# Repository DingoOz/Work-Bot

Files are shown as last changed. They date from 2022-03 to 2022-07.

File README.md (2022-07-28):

# Work-Bot
2022 Semester 2

//TODO
* document code more
* factor the code to use functions more
* document a possible Finite State Machine that calls these functions
* implement a watchdog timer to detect if robot is not making progress

== Diagnostic Routine ==
Possibly create a separate program to act as a diagnostic program to test all functions of the hardward.

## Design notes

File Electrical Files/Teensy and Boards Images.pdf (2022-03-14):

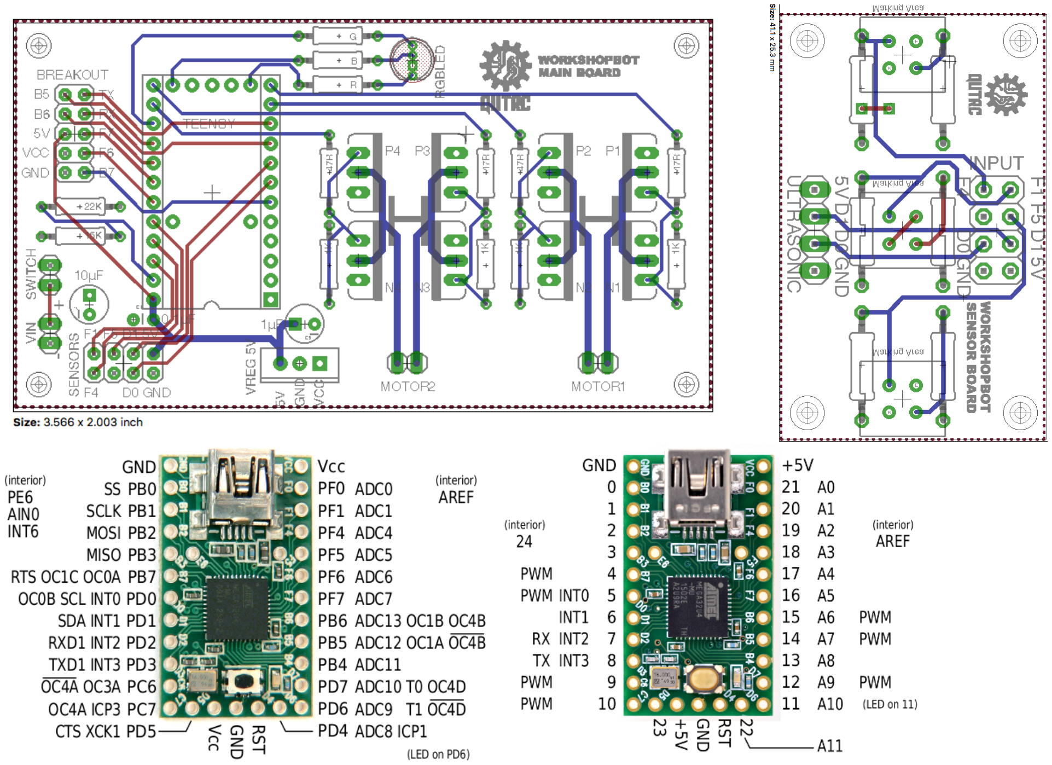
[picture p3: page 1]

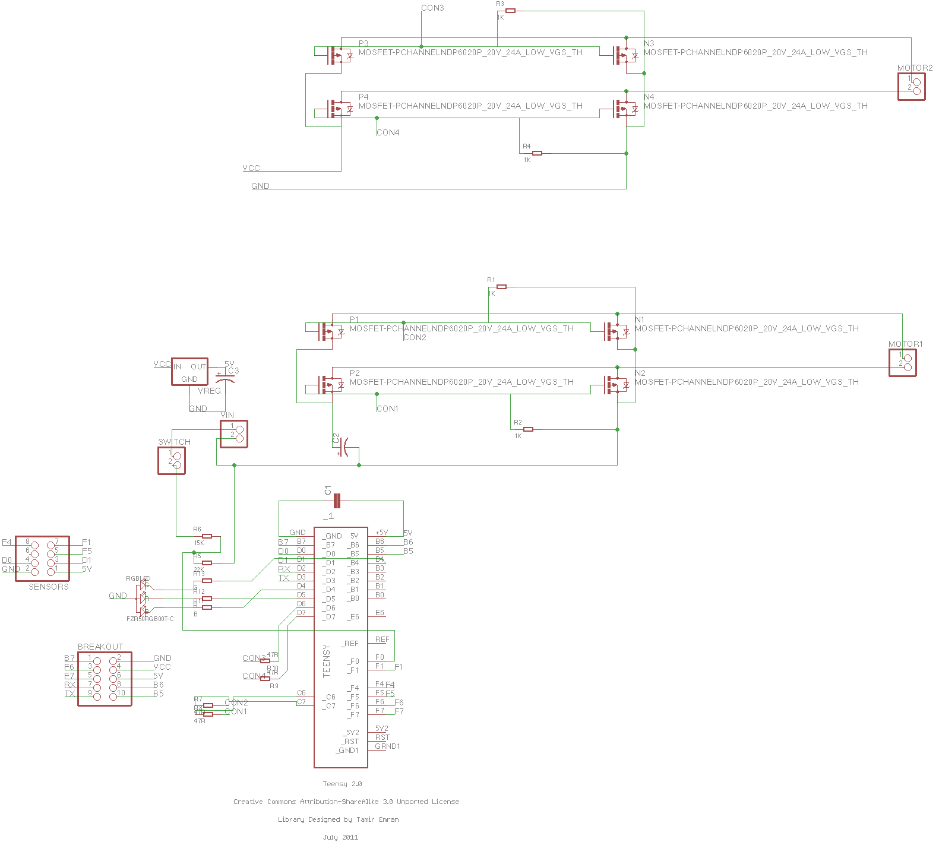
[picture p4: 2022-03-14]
Electrical Files/Workbot2017 - Schematic.png

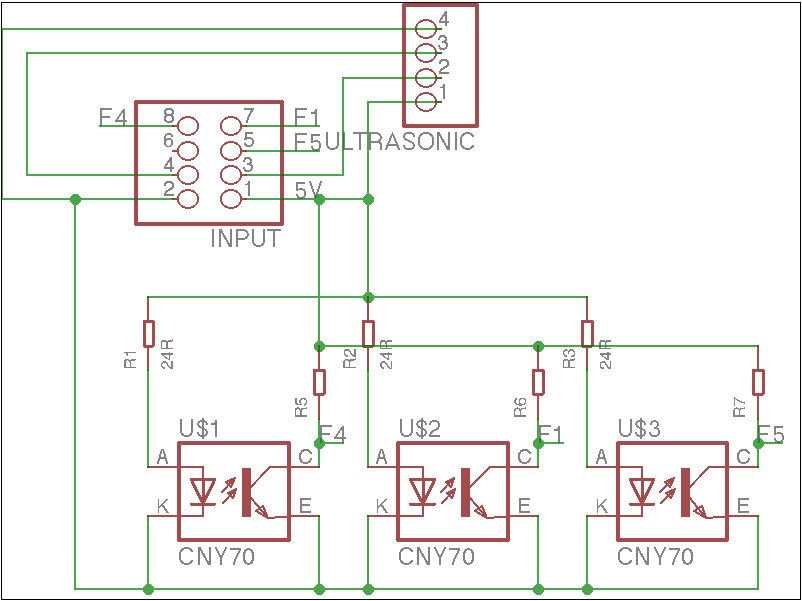
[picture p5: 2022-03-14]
Electrical Files/IR Sensor Schematic.png

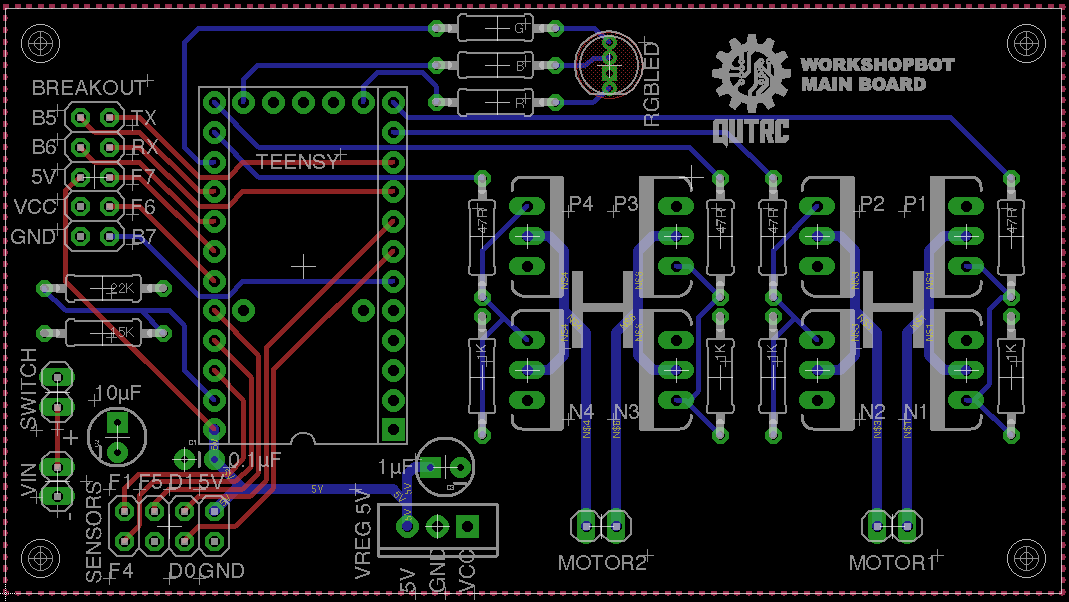
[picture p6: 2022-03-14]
Electrical Files/Main PCB Black.png

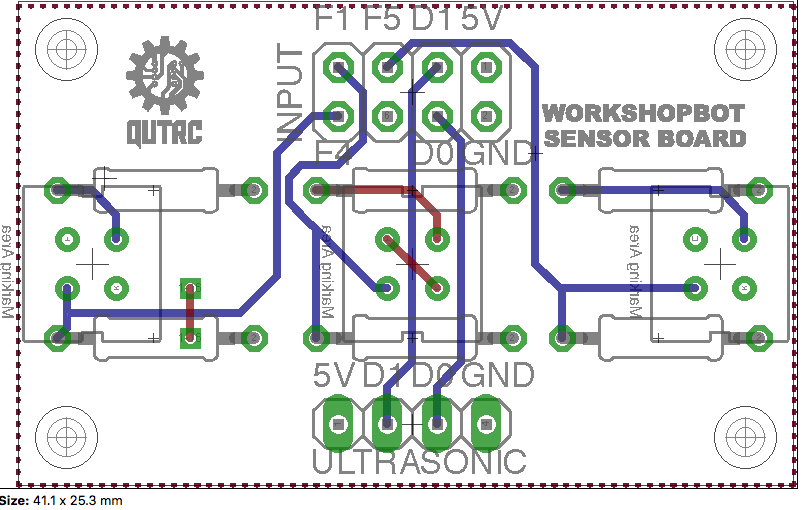
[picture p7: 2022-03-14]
Electrical Files/IR Sensor Board.png

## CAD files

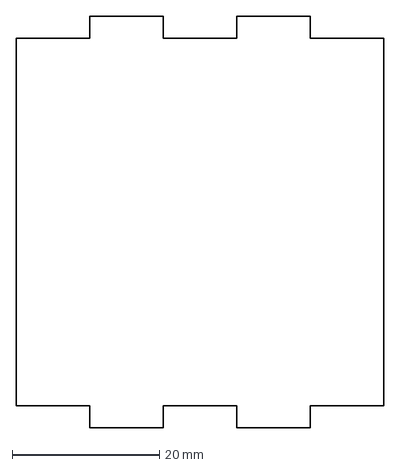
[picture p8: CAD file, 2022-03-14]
Mechanical Files/Top_box.dxf
50.0 x 56.0 mm

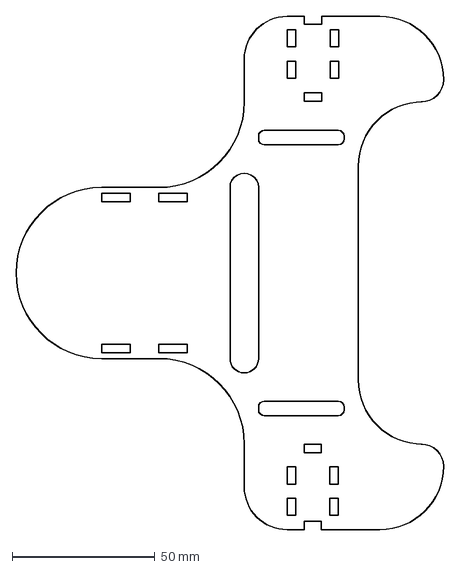
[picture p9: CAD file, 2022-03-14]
Mechanical Files/Torus_base_v1.dxf
150.0 x 180.0 mm

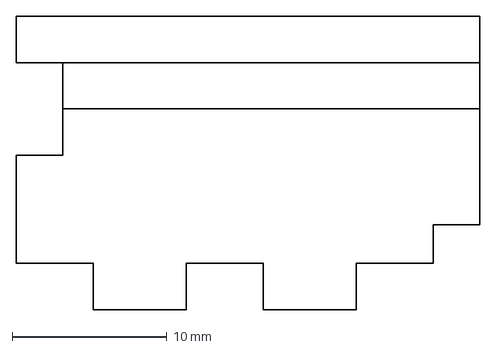
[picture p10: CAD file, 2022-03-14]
Mechanical Files/Motor_side.dxf
30.0 x 19.0 mm

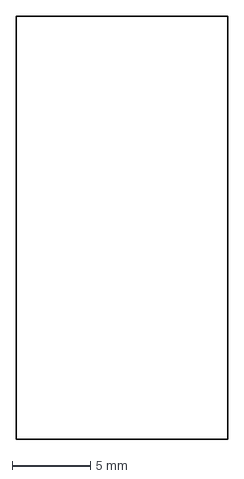
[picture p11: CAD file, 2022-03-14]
Mechanical Files/Motor_top.dxf
13.5 x 27.0 mm

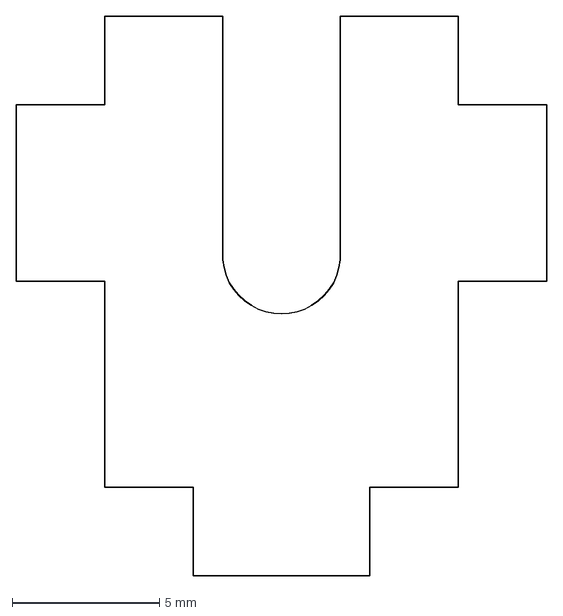
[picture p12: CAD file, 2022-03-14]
Mechanical Files/Motor_front.dxf
18.0 x 19.0 mm

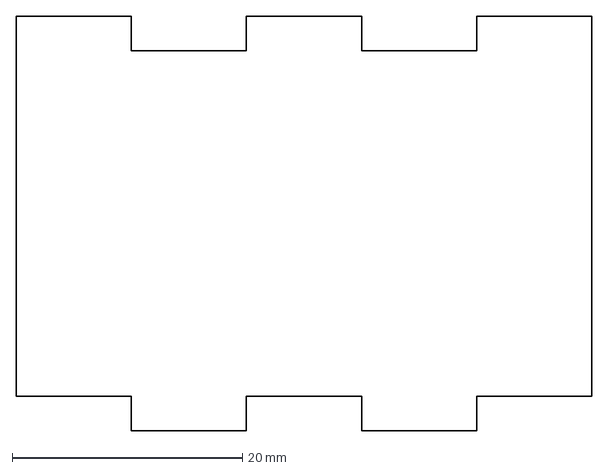
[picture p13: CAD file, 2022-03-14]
Mechanical Files/Side_box.dxf
50.0 x 36.0 mm

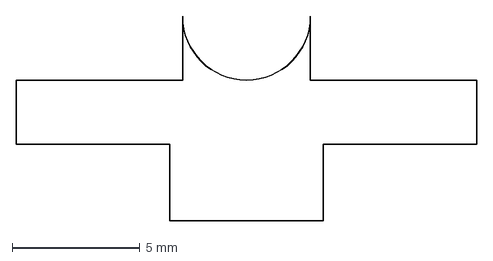
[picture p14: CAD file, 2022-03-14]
Mechanical Files/Motor_back.dxf
18.0 x 8.00 mm

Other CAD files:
Mechanical Files/Flexible shapes examples.dwg
Mechanical Files/Torus_v1.dwg

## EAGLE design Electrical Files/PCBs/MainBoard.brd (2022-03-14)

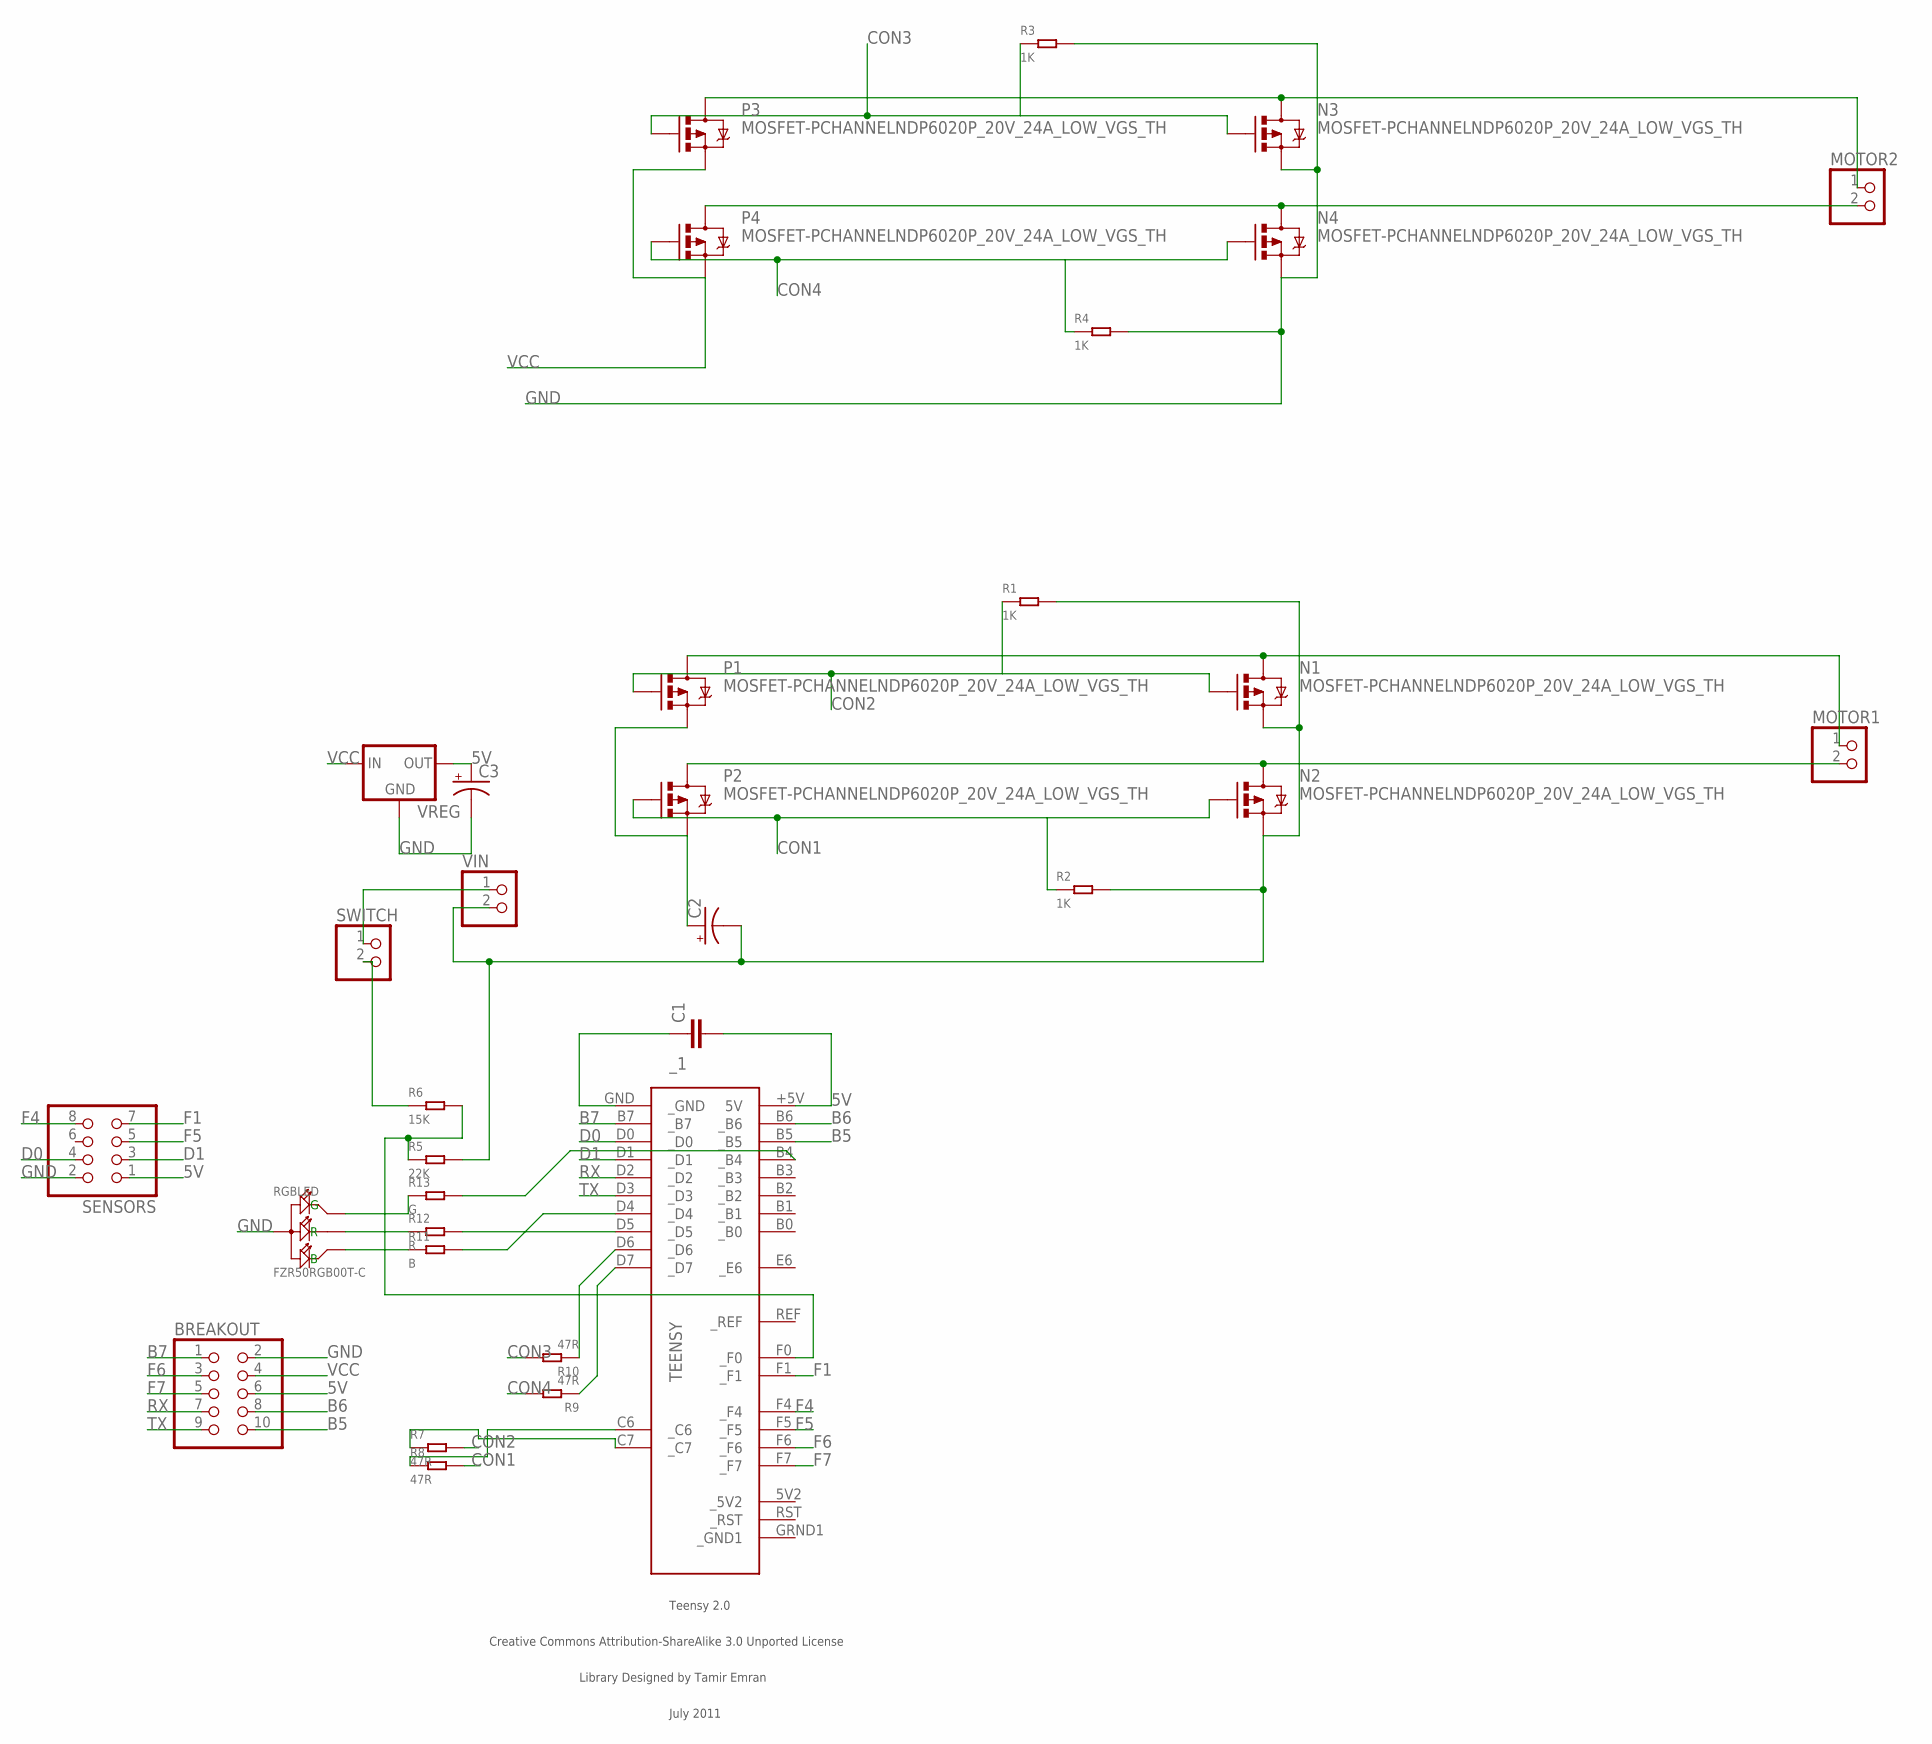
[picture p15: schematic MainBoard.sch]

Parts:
BREAKOUT: PINHD-2X5; 2X05
C1: CAPPTH; CAP-PTH-SMALL
C2, C3: CAP_POLPTH2; CPOL-RADIAL-10UF-25V
MOTOR1, MOTOR2: PINHD-1X2; 1X02
N1, N2, N3, N4: MOSFET-PCHANNELNDP6020P_20V_24A_LOW_VGS_TH; TO220V
P1, P2, P3, P4: MOSFET-PCHANNELNDP6020P_20V_24A_LOW_VGS_TH; TO220V
R1, R2, R3, R4: 1K; PR-D2.3XL6.5MM
R5: 22K; PR-D2.3XL6.5MM
R6: 15K; PR-D2.3XL6.5MM
R7, R8, R9, R10: 47R; PR-D2.3XL6.5MM
R11: B; PR-D2.3XL6.5MM
R12: R; PR-D2.3XL6.5MM
R13: G; PR-D2.3XL6.5MM
RGBLED: FZR50RGB00T-C; LED4-1.3-D5.0MM
SENSORS: PINHD-2X4; 2X04
SWITCH: PINHD-1X2; 1X02
VIN: PINHD-1X2; 1X02
VREG: V_REG_78XXSINK; TO220-IGO
_1: TEENSY

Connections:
5V: BREAKOUT.6, C1.2, C3.1 (+), SENSORS.1, VREG.OUT, _1.+5V (5V)
B5: BREAKOUT.10, _1.B5 (_B5)
B6: BREAKOUT.8, _1.B6 (_B6)
B7: BREAKOUT.1, _1.B7 (_B7)
CON1: N2.1 (G), P2.1 (G), R2.1, R8.2
CON2: N1.1 (G), P1.1 (G), R1.1, R7.2
CON3: N3.1 (G), P3.1 (G), R3.1, R10.2
CON4: N4.1 (G), P4.1 (G), R4.1, R9.2
D0: SENSORS.4, _1.D0 (_D0)
D1: SENSORS.3, _1.D1 (_D1)
F1: SENSORS.7, _1.F1 (_F1)
F4: SENSORS.8, _1.F4 (_F4)
F5: SENSORS.5, _1.F5 (_F5)
F6: BREAKOUT.3, _1.F6 (_F6)
F7: BREAKOUT.5, _1.F7 (_F7)
GND: BREAKOUT.2, C1.1, C2.2 (-), C3.2 (-), N1.3 (S), N2.3 (S), N3.3 (S), N4.3 (S), R1.2, R2.2, R3.2, R4.2, R5.2, RGBLED.C (+), SENSORS.2, VIN.2, VREG.GND, _1.GND (_GND)
unnamed: MOTOR1.1, N1.2 (D), P1.2 (D)
unnamed: R10.1, _1.D6 (_D6)
unnamed: MOTOR1.2, N2.2 (D), P2.2 (D)
unnamed: MOTOR2.2, N4.2 (D), P4.2 (D)
unnamed: R9.1, _1.D7 (_D7)
unnamed: MOTOR2.1, N3.2 (D), P3.2 (D)
unnamed: R7.1, _1.C7 (_C7)
unnamed: R8.1, _1.C6 (_C6)
unnamed: R5.1, R6.2, _1.F0 (_F0)
unnamed: R11.2, _1.D4 (_D4)
unnamed: SWITCH.1, VIN.1
unnamed: R12.2, _1.D5 (_D5)
unnamed: R13.2, _1.B4 (_B4)
unnamed: R13.1, RGBLED.G
unnamed: R12.1, RGBLED.R
unnamed: R11.1, RGBLED.B
RX: BREAKOUT.7, _1.D2 (_D2)
TX: BREAKOUT.9, _1.D3 (_D3)
VCC: BREAKOUT.4, C2.1 (+), P1.3 (S), P2.3 (S), P3.3 (S), P4.3 (S), R6.1, SWITCH.2, VREG.IN

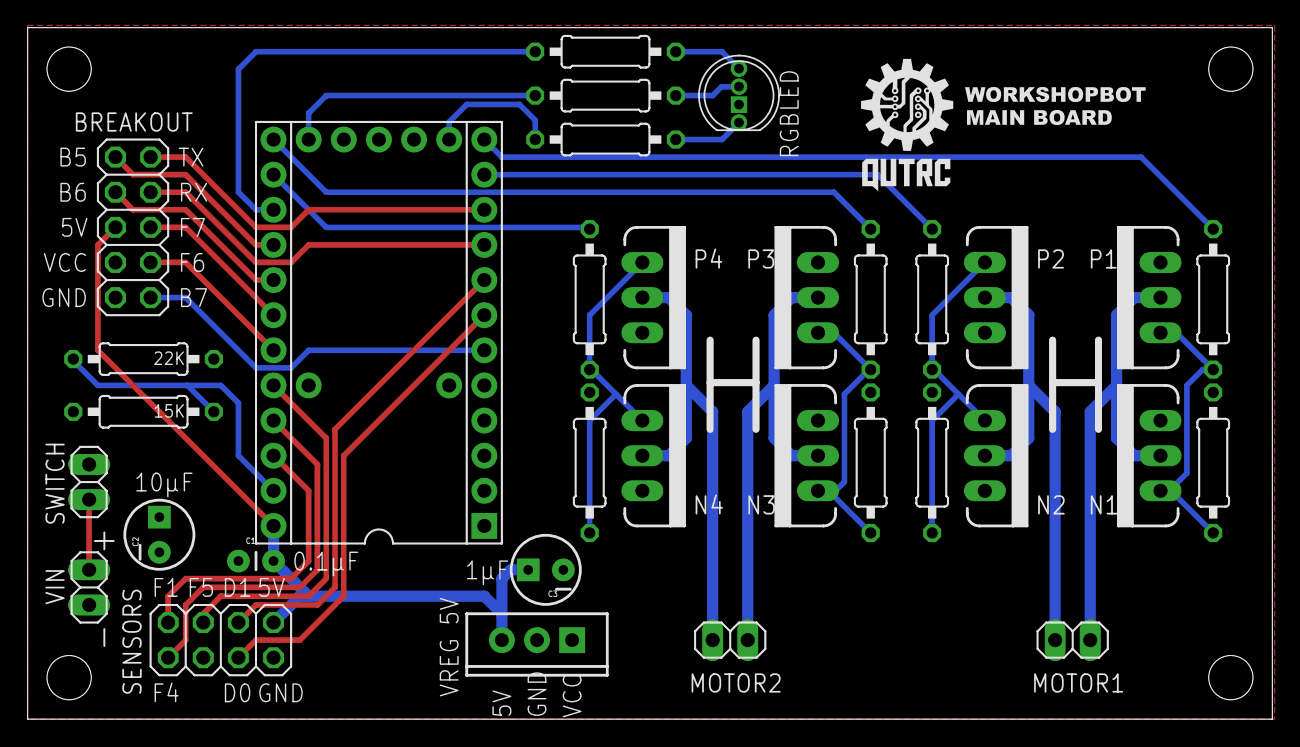
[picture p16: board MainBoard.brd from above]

Board: 2 copper layers, 90.0 x 50.0 mm, 34 parts (0 on the bottom side), 35 nets.

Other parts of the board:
U$1: LOGO1

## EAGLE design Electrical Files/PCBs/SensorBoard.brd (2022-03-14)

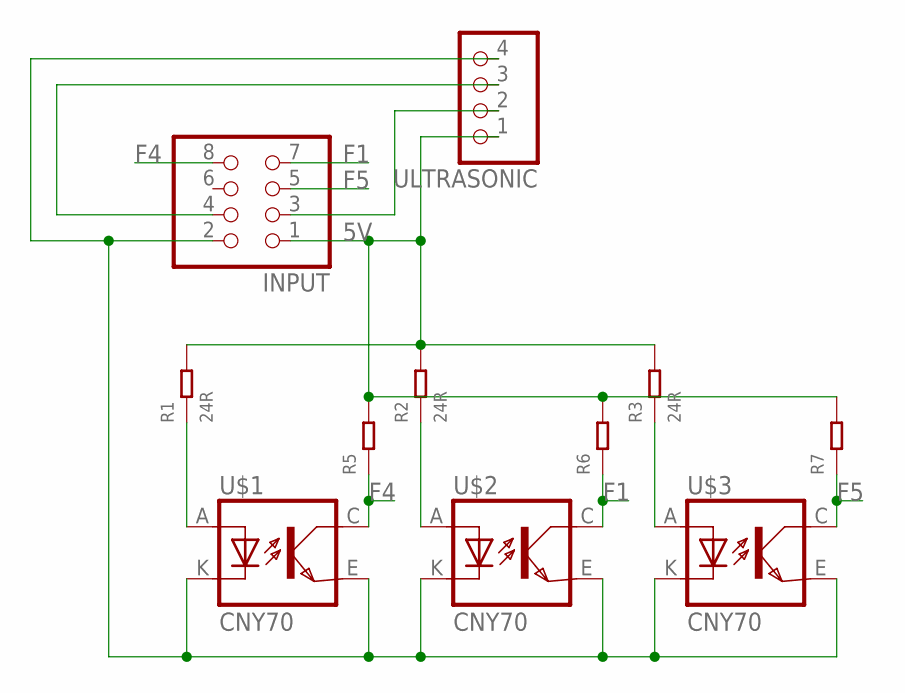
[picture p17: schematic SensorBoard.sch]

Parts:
INPUT: PINHD-2X4; 2X04
R1, R2, R3: 24R; PR-D2.3XL6.5MM
R5, R6, R7: DIP-RES-0R-5%-1/4W(2P-D2.3XL6.5MM); PR-D2.3XL6.5MM
U$1, U$2, U$3: CNY70; 4
ULTRASONIC: PINHD-1X4; 1X04

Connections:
5V: INPUT.1, R1.2, R2.2, R3.2, R5.2, R6.2, R7.2, ULTRASONIC.1
F1: INPUT.7, R6.1, U$2.C (COL)
F4: INPUT.8, R5.1, U$1.C (COL)
F5: INPUT.5, R7.1, U$3.C (COL)
GND: INPUT.2, U$1.E (EMI), U$1.K (C), U$2.E (EMI), U$2.K (C), U$3.E (EMI), U$3.K (C), ULTRASONIC.4
unnamed: R2.1, U$2.A
unnamed: INPUT.3, ULTRASONIC.2
unnamed: INPUT.4, ULTRASONIC.3
unnamed: R3.1, U$3.A
unnamed: R1.1, U$1.A

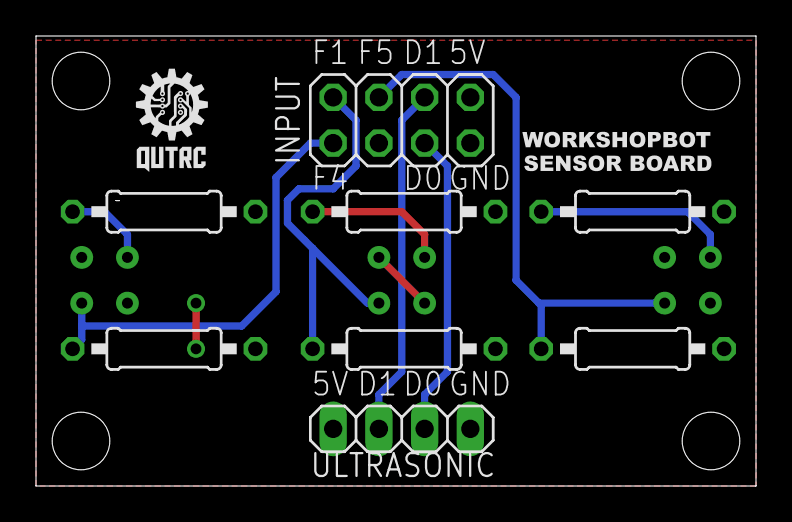
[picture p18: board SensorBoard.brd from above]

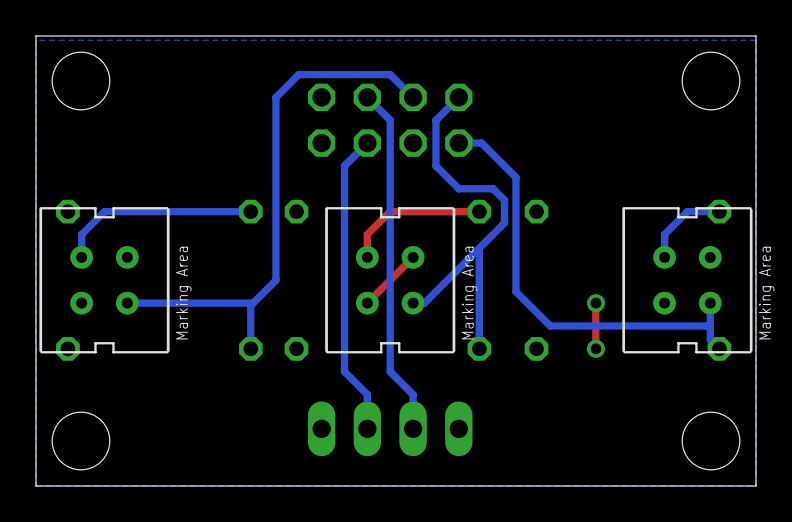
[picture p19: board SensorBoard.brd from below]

Board: 2 copper layers, 40.0 x 25.0 mm, 13 parts (3 on the bottom side), 10 nets.

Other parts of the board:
U$4: LOGO21
U$5: LOGO22

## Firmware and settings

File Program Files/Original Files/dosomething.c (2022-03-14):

#include <NewPing.h>

//Bunch of pins
#define RLED 23
#define GLED 13
#define BLED 22

#define LIR A3
#define CIR A1
#define RIR A2

#define VDIV A0

//Motor pins
#define LF 12
#define LB 14
#define RF 9
#define RB 10

//Ultrasonic pins
#define USTRIGGER 6
#define USECHO 5

#define STOP_THRESH 2

//Other pin setup stuff
NewPing sonar(USTRIGGER, USECHO);
int LED[3] = {RLED, GLED, BLED};
int IR[3] = {LIR, CIR, RIR};
int MOT[2][2] = {{LF, LB}, {RF, RB}};

//Sets up everything
void setup() {
  //LEDS and IR
  for (int i = 0; i < 3; i++) {
    pinMode(LED[i], OUTPUT);
    pinMode(IR[i], INPUT);
  }

  //Voltage Divider, for checking battery
  pinMode(VDIV, INPUT);

  //Serial, for outputting... stuff.
  Serial.begin(9600);

}

//The uncommented code should just make the robot rock back and forth every 8 seconds
void loop() {
  for (int i = 0; i < 200; i++) {
    setMotors(i, i);
    delay(10);
  }
  for (int i = 200; i > 0; i--) {
    setMotors(i, i);
    delay(10);
  }
  for (int i = 0; i < 200; i++) {
    setMotors(-i, -i);
    delay(10);
  }
  for (int i = 200; i > 0; i--) {
    setMotors(-i, -i);
    delay(10);
  }

  delay(1000);
  
  /*
  for (int i = 0; i < 3; i++) {
    digitalWrite(LED[(i-1>=0) ? i-1 : 2], 0);
    digitalWrite(LED[i], 1);
    //Serial.println(sonar.ping_cm());
    //Serial.println(checkIR(IR[i]));
    delay(1000);
  }
  */
  
  
}

//returns true if on white, false if on black/edge
bool checkIR(int ir) {
  return analogRead(ir) < 500;
}

//returns true if the battery has enough juice
bool checkBatt() {
  return analogRead(VDIV) > 512;
}


//each motor between -255 and 255 (though best values are < 200)
void setMotors(int left, int right) {
  int val[2] = {left, right};
  for (int i = 0; i < 2; i++) {
    if (val[i] == 0) for (int j = 0; j < 2; j++) analogWrite(MOT[i][j], 0);
    else {
      bool dir = val[i] > 0;
      analogWrite(MOT[i][!dir], 0);
      analogWrite(MOT[i][dir], abs(val[i]));
    }
  }
}

void followLineUntilJunction() {
  int confirm = 0; 
  uint8_t reading;
  unsigned long t = millis();
  
  while (true) {
    unsigned long delta = millis() - t;
    if (millis() - t < 100) {
      delay(100-delta);
      continue;
    }
    t = millis();

    reading = 0;
    for (int i = 0; i < 3; i++) reading =+ checkIR(IR[i]) << i;
    
    if (reading == 0b000 || reading == 0b101 || reading == 0b111) {
      if (confirm <= STOP_THRESH) {
        confirm++;
        continue;
      }
      else {
        setMotors(0, 0);
        return;
      }
    }
    confirm = 0;
    
    if (reading == 0b100 || reading == 0b110) 
      setMotors(100, 0);
    else if (reading == 0b001 || reading == 0b011)   
      setMotors(0, 100);
    else 
      setMotors(75, 75);
  }
  
}

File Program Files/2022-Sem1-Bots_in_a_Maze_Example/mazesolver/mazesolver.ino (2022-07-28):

/*
 * QUT Robotics Work Bot
 * Hardware is based on a Teensy 2.0, SR04, 3 IR sensors and 
 * custom H-bridges driving two 6v geared DC motors.
 */

#include "mazesolver.h"
#include <NewPing.h>  //to drive the Ultrasonic SR04 sensor


//***** Pin Defintions *****

// RGB LED 
#define RLED 23
#define GLED 13
#define BLED 22

#define LIR A3
#define CIR A1
#define RIR A2

// Battery Voltage ADC
#define VDIV A0

//Motor H-Bridge
#define LF 12
#define LB 14
#define RF 9
#define RB 10

//Ultrasonic Sensor SR04
#define USTRIGGER 6
#define USECHO 5
//*************************

//define constants
#define STOP_THRESH 2
#define STOP_THRESH_DIST 5

//Other pin setup stuff
NewPing sonar(USTRIGGER, USECHO);
int LED[3] = {RLED, GLED, BLED};
int IR[3] = {LIR, CIR, RIR};
int MOT[2][2] = {{LF, LB}, {RF, RB}};

int confirm; 
int confirm_dist; 
uint8_t reading;
unsigned long t;;

//*****************************************************************************
// Function: setup()
// Sets up everything, runs once
//*****************************************************************************

void setup() {
  //LEDS and IR
  for (int i = 0; i < 3; i++) {
    pinMode(LED[i], OUTPUT);
    pinMode(IR[i], INPUT);
  }

  //Voltage Divider, for checking battery
  pinMode(VDIV, INPUT);

  //Serial, for outputting... stuff.
  Serial.begin(9600);

  confirm = 0; 
  confirm_dist = 0;
  reading;
  t = millis();

  //Confirm Battery has enough Voltage
  if (!checkBatt()) {
    //Battery was measured as not enough Voltage therefore blink LED Red 5 times, pause, blink 5 times then repeat.
    while(true){ //never ending loop 
      //ADD RED LED BLINK ROUTINE HERE
      int i = 0;
      for (i=1; i <=5; i++){
        digitalWrite(LED[0], 1); //red on
        delay(500);
      }
      delay(3000);
      }
    
  }

}


void loop() {
 
 
  //Serial.println(sonar.ping_cm());


  if (sonar.ping_cm() < 3) {
    if (confirm_dist >= STOP_THRESH_DIST) {
      wallahead();
      confirm_dist = 0;
      Serial.println("hit");
    }
    else{
      confirm_dist++;
    }      
  }

  followLineUntilJunction();
  
  
}

//returns true if on white, false if on black/edge
bool checkIR(int ir) {
  return analogRead(ir) < 500;
}

//returns true if the battery has enough juice
bool checkBatt() {
  return analogRead(VDIV) > 512;
}


//each motor between -255 and 255 (though best values are < 200)
void setMotors(int left, int right) {
  int val[2] = {left, right};
  for (int i = 0; i < 2; i++) {
    if (val[i] == 0) for (int j = 0; j < 2; j++) analogWrite(MOT[i][j], 0);
    else {
      bool dir = val[i] > 0;
      analogWrite(MOT[i][!dir], 0);
      analogWrite(MOT[i][dir], abs(val[i]));
    }
  }
}

//******************************************************************************************
// Function: wallahead()
// This function is called to react to the detection of an obstacle
//******************************************************************************************
void wallahead() {
  setMotors(-50, 50);  //start spinning robot
  delay(1500);  //wait for 1.5 seconds
} //return to calling function.

void followLineUntilJunction() {
  
  
  //while (true) {
    unsigned long delta = millis() - t;
    if (millis() - t < 100) {
      delay(100-delta);
      //continue;
    }
    t = millis();

    reading = 0;
    for (int i = 0; i < 3; i++) reading += checkIR(IR[i]) << i;

    Serial.println(reading);
    
    if (reading == 0b000 || reading == 0b101 || reading == 0b111) {
      if (confirm <= STOP_THRESH) {
        confirm++;
        //continue;
      }
      else {
        //setMotors(0, 0);
        digitalWrite(LED[0], 0); //red
        digitalWrite(LED[1], 0); //green
        digitalWrite(LED[2], 0); //blue
        confirm = 0;
        return;
      }
    }
    
    
    if (reading == 0b011) {
      setMotors(45, 80);
      //setMotors(80, 30);
      digitalWrite(LED[0], 1); //red
      digitalWrite(LED[1], 0); //green
      digitalWrite(LED[2], 0); //blue
    }
    else if (reading == 0b110) {  
      setMotors(80, 45);
      //setMotors(30, 80);
      digitalWrite(LED[0], 0); //red
      digitalWrite(LED[1], 0); //green
      digitalWrite(LED[2], 1); //blue
    }
    else if (reading == 0b001) {
      setMotors(50, 75);
      //setMotors(100, 30);
      digitalWrite(LED[0], 1); //red
      digitalWrite(LED[1], 1); //green
      digitalWrite(LED[2], 0); //blue
    }
    else if (reading == 0b100) {  
      setMotors(75, 30);
      //setMotors(30, 100);
      digitalWrite(LED[0], 0); //red
      digitalWrite(LED[1], 1); //green
      digitalWrite(LED[2], 1); //blue
    }
    else if (reading == 0b101) {
      setMotors(50, 50);
      digitalWrite(LED[0], 0); //red
      digitalWrite(LED[1], 1); //green
      digitalWrite(LED[2], 0); //blue
    }
  //}
  
}

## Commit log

2022-03-14 Adding original files and new files
    Creation of github repo for 2017 workshop called workbots. Adding the original files from the google drive alogn with example maze solving and line following code.
    [Flexible shapes examples.dwg, MainBoard.brd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]
2022-07-28 Added header and battery check
    Added mazesolver.h
    Added the beginnings of a Initial Battery Check routine that stops and blinks RED if battery is low
    Moved some unused code into a Diagnostics routine file (started, not yet finished)
2022-07-28 Update mazesolver.ino
    Added red light blink loop if the battery voltage is measured as too low to run. Red LED blinks 5 times, waits 3 seconds, blinks 5 time...forever.
    [mazesolver.ino]

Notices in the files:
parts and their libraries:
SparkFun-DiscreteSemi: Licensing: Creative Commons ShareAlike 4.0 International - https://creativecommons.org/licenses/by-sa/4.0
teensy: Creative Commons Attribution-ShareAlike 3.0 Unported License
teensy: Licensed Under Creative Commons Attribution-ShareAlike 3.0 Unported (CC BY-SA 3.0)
